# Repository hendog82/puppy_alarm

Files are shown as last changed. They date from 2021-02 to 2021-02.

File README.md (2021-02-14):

# Puppy Alarm Clock
Do you hate waking up to your alarm clock? Well, now you can wake up to your puppy licking your face instead. 

This gadget allows you to set a wake up time, and then it will open your dogs crate at the specified time, allowing your dog to jump on your bed and wake you up. 

### Firmware
The firmware is based on the [restful server example](https://github.com/espressif/esp-idf/tree/master/examples/protocols/http_server/restful_server) from the ESP-IDF. The firmware connects to the WiFi network and hosts a local website (so that any device connected to the same network can access it).

Users can connect to this local web page to set the alarm time (using post requests). The ESP gets the current time using NTP, and if the times match the ESP will turn on the motor, opening the dog create. 

### Webpage
The webpage has a live clock and selectable options to set the wake up time, which is then sent to the ESP 32 using a post request. The source code is in the `/front/web-demo/dist` folder.

### Hardware
I generated a simple 2-layer PCB using EAGLE. The files are in the `/board_files` folder. This PCB connects the [ESP-32 huzzah Dev board](https://www.adafruit.com/product/3405) to an H-Bridge that can drive the motor in either direction, and to a button that is used to reset the motor position (or any other desired function. It also has LED's to indicate motor spin direction. The board is powered using 5V from the micro-usb port on the dev board.

#### Pin Assignment:
The following GPIO's of the ESP32 Dev Board are connected

| ESP32  | Function |
| --- | --- |
| GPIO27 | Motor Forwards |
| GPIO33 | Motor Backwards|
| GPIO16 | Button Input |

### 3D Printed Housing
The STL files for the 3D printed housing are in the `/housing` folder.

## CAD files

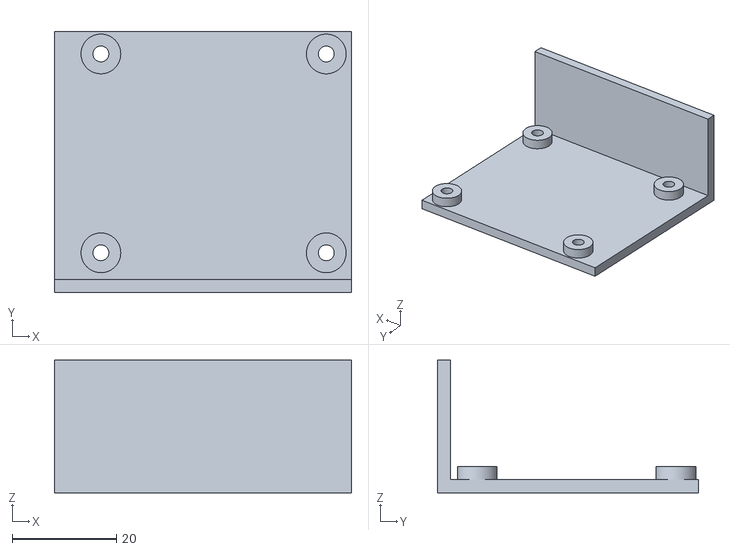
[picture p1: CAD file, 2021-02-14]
Housing/alarm housing v3.stl
56.9 x 50.0 x 25.4

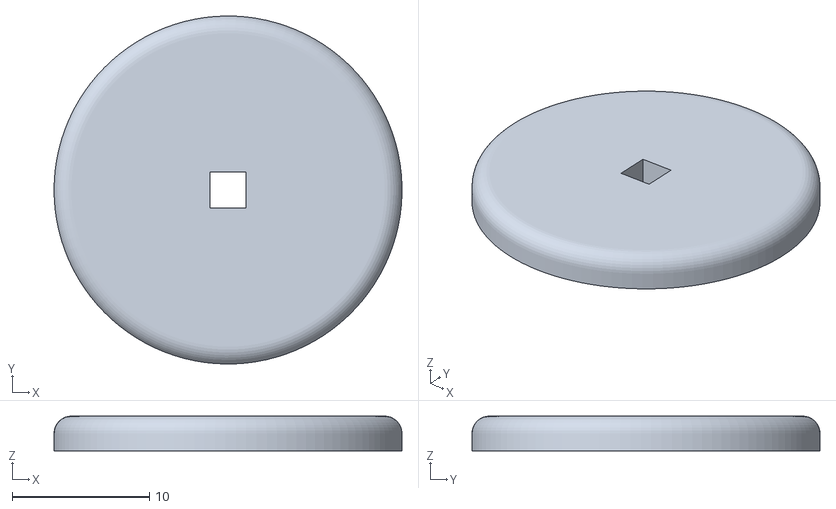
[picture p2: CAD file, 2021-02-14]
Housing/alarm wheel v1.stl
25.4 x 25.4 x 2.54

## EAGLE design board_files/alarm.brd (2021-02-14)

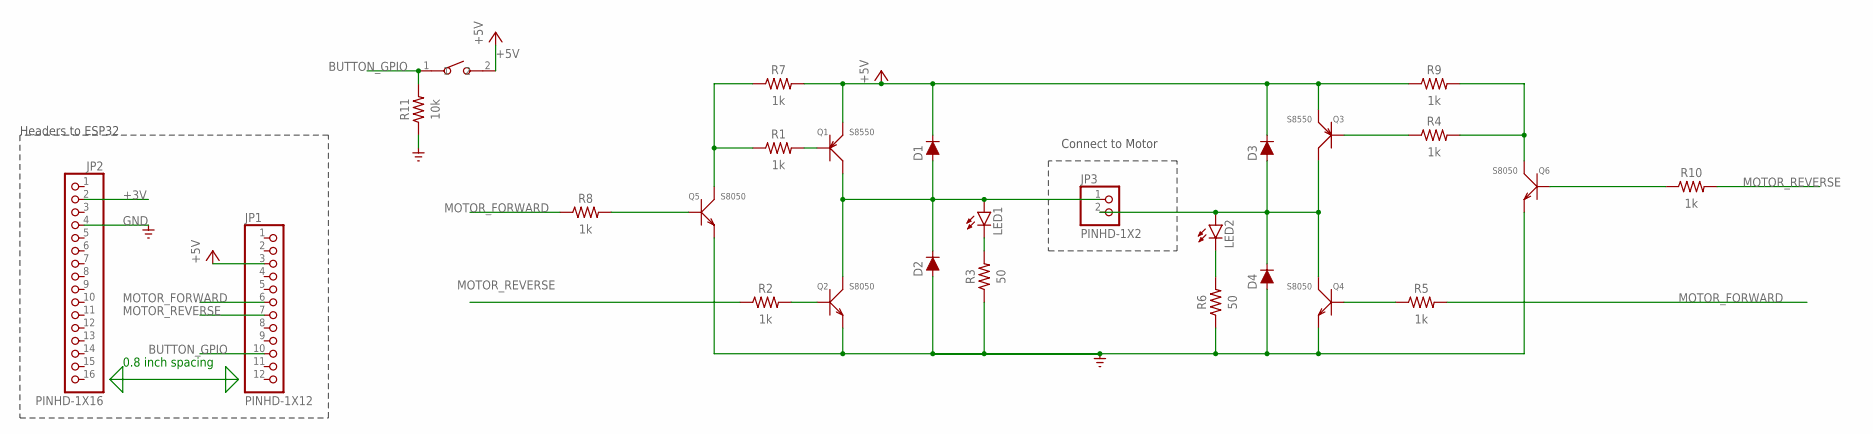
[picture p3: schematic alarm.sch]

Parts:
D1, D2, D3, D4: 250mA/100V; SOD-323
JP1: PINHD-1X12; 1X12
JP2: PINHD-1X16; 1X16
JP3: PINHD-1X2; 1X02
LED1: LED-GREEN0603; 0603-GREEN
LED2: LED-ORANGE0603; 0603-ORANGE
Q1, Q3: S8550; SOT-23
Q2, Q4, Q5, Q6: S8050; SOT-23
R1, R2, R4, R5, R7, R8, R9, R10: 1k; RESC1608X60
R3, R6: 50; RESC1608X60
R11: 10k; RESC1608X60
SW1: B3U-1000P-2P-SMD; SW2-2.6-3.0X2.5X1.2+0.4MM

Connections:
+3V: JP2.2
+5V: D1.C, D3.C, JP1.3, Q1.2 (E), Q3.2 (E), R7.2, R9.1, SW1.2
BUTTON_GPIO: JP1.10, R11.2, SW1.1
GND: D2.A, D4.A, JP2.4, Q2.2 (E), Q4.2 (E), Q5.2 (E), Q6.2 (E), R3.1, R6.1, R11.1
MOTOR_BLACK: D3.A, D4.C, JP3.2, LED2.A, Q3.3 (C), Q4.3 (C)
MOTOR_FORWARD: JP1.6, R5.2, R8.1
MOTOR_RED: D1.A, D2.C, JP3.1, LED1.A, Q1.3 (C), Q2.3 (C)
MOTOR_REVERSE: JP1.7, R2.1, R10.2
unnamed: Q1.1 (B), R1.2
unnamed: Q2.1 (B), R2.2
unnamed: LED1.C, R3.2
unnamed: Q5.1 (B), R8.2
unnamed: Q3.1 (B), R4.1
unnamed: Q4.1 (B), R5.1
unnamed: LED2.C, R6.2
unnamed: Q5.3 (C), R1.1, R7.1
unnamed: Q6.3 (C), R4.2, R9.2
unnamed: Q6.1 (B), R10.1

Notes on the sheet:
0.8 inch spacing
Headers to ESP32
Connect to Motor

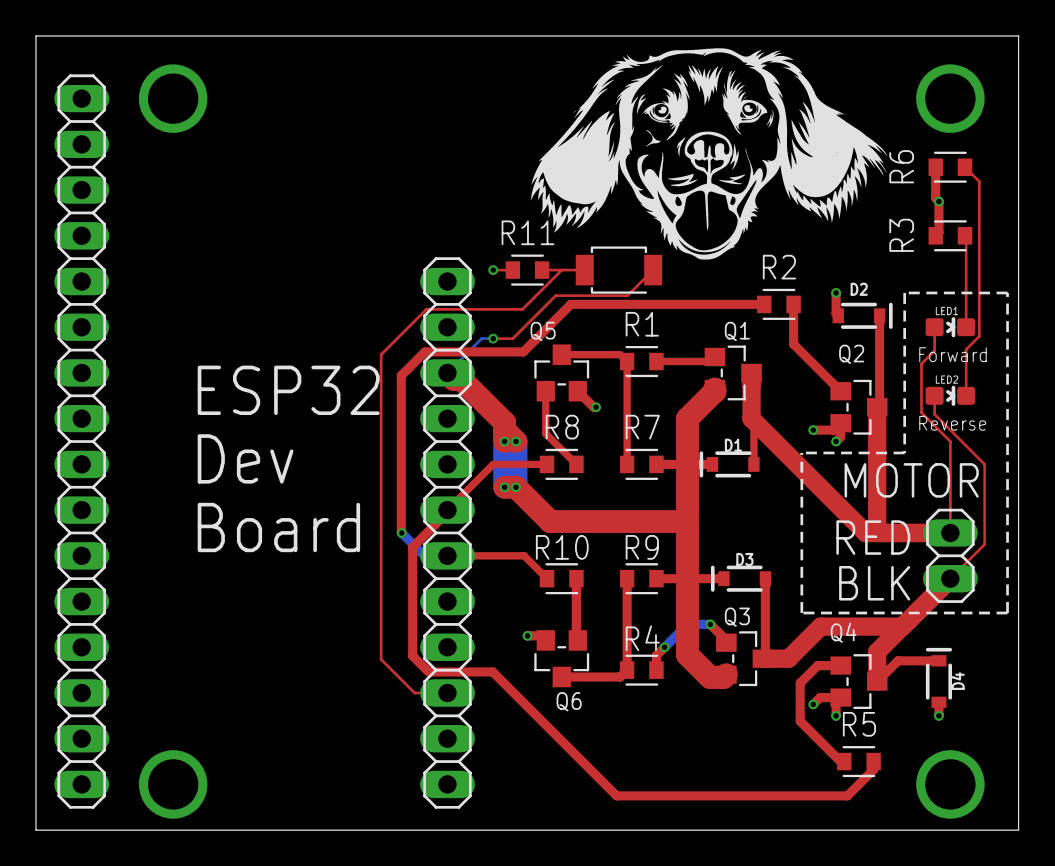
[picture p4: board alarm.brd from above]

Board: 2 copper layers, 54.6 x 44.1 mm, 27 parts (0 on the bottom side), 17 nets.

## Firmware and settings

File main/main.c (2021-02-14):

#include "sdkconfig.h"
#include <time.h>
#include <sys/time.h>
#include "driver/gpio.h"
#include "esp_vfs_semihost.h"
#include "esp_vfs_fat.h"
#include "esp_spiffs.h"
#include "sdmmc_cmd.h"
#include "nvs_flash.h"
#include "esp_netif.h"
#include "esp_event.h"
#include "esp_log.h"
#include "esp_sntp.h"

#include "server.h"
#include "gpio_if.h"

#include "mdns.h"
#include "lwip/apps/netbiosns.h"
#include "protocol_examples_common.h"
#if CONFIG_EXAMPLE_WEB_DEPLOY_SD
#include "driver/sdmmc_host.h"
#endif

#define MDNS_INSTANCE "esp home web server"

static const char *TAG = "main";


static void initialise_mdns(void)
{
    mdns_init();
    mdns_hostname_set(CONFIG_EXAMPLE_MDNS_HOST_NAME);
    mdns_instance_name_set(MDNS_INSTANCE);

    mdns_txt_item_t serviceTxtData[] = {
        {"board", "esp32"},
        {"path", "/"}
    };

    ESP_ERROR_CHECK(mdns_service_add("ESP32-WebServer", "_http", "_tcp", 80, serviceTxtData,
                                     sizeof(serviceTxtData) / sizeof(serviceTxtData[0])));
}

#if CONFIG_EXAMPLE_WEB_DEPLOY_SEMIHOST
esp_err_t init_fs(void)
{
    esp_err_t ret = esp_vfs_semihost_register(CONFIG_EXAMPLE_WEB_MOUNT_POINT, CONFIG_EXAMPLE_HOST_PATH_TO_MOUNT);
    if (ret != ESP_OK) {
        ESP_LOGE(TAG, "Failed to register semihost driver (%s)!", esp_err_to_name(ret));
        return ESP_FAIL;
    }
    return ESP_OK;
}
#endif

#if CONFIG_EXAMPLE_WEB_DEPLOY_SD
esp_err_t init_fs(void)
{
    sdmmc_host_t host = SDMMC_HOST_DEFAULT();
    sdmmc_slot_config_t slot_config = SDMMC_SLOT_CONFIG_DEFAULT();

    gpio_set_pull_mode(15, GPIO_PULLUP_ONLY); // CMD
    gpio_set_pull_mode(2, GPIO_PULLUP_ONLY);  // D0
    gpio_set_pull_mode(4, GPIO_PULLUP_ONLY);  // D1
    gpio_set_pull_mode(12, GPIO_PULLUP_ONLY); // D2
    gpio_set_pull_mode(13, GPIO_PULLUP_ONLY); // D3

    esp_vfs_fat_sdmmc_mount_config_t mount_config = {
        .format_if_mount_failed = true,
        .max_files = 4,
        .allocation_unit_size = 16 * 1024
    };

    sdmmc_card_t *card;
    esp_err_t ret = esp_vfs_fat_sdmmc_mount(CONFIG_EXAMPLE_WEB_MOUNT_POINT, &host, &slot_config, &mount_config, &card);
    if (ret != ESP_OK) {
        if (ret == ESP_FAIL) {
            ESP_LOGE(TAG, "Failed to mount filesystem.");
        } else {
            ESP_LOGE(TAG, "Failed to initialize the card (%s)", esp_err_to_name(ret));
        }
        return ESP_FAIL;
    }
    /* print card info if mount successfully */
    sdmmc_card_print_info(stdout, card);
    return ESP_OK;
}
#endif

#if CONFIG_EXAMPLE_WEB_DEPLOY_SF
esp_err_t init_fs(void)
{
    esp_vfs_spiffs_conf_t conf = {
        .base_path = CONFIG_EXAMPLE_WEB_MOUNT_POINT,
        .partition_label = NULL,
        .max_files = 5,
        .format_if_mount_failed = false
    };
    esp_err_t ret = esp_vfs_spiffs_register(&conf);

    if (ret != ESP_OK) {
        if (ret == ESP_FAIL) {
            ESP_LOGE(TAG, "Failed to mount or format filesystem");
        } else if (ret == ESP_ERR_NOT_FOUND) {
            ESP_LOGE(TAG, "Failed to find SPIFFS partition");
        } else {
            ESP_LOGE(TAG, "Failed to initialize SPIFFS (%s)", esp_err_to_name(ret));
        }
        return ESP_FAIL;
    }

    size_t total = 0, used = 0;
    ret = esp_spiffs_info(NULL, &total, &used);
    if (ret != ESP_OK) {
        ESP_LOGE(TAG, "Failed to get SPIFFS partition information (%s)", esp_err_to_name(ret));
    } else {
        ESP_LOGI(TAG, "Partition size: total: %d, used: %d", total, used);
    }
    return ESP_OK;
}
#endif


void app_main(void)
{
    ESP_ERROR_CHECK(nvs_flash_init());
    ESP_ERROR_CHECK(esp_netif_init());
    ESP_ERROR_CHECK(esp_event_loop_create_default());
    initialise_mdns();
    netbiosns_init();
    netbiosns_set_name(CONFIG_EXAMPLE_MDNS_HOST_NAME);

    ESP_ERROR_CHECK(example_connect());
    ESP_ERROR_CHECK(init_fs());
    ESP_ERROR_CHECK(start_rest_server(CONFIG_EXAMPLE_WEB_MOUNT_POINT));

    ESP_LOGI(TAG, "Getting Current Time using NTP");

    sntp_setoperatingmode(SNTP_OPMODE_POLL);
    sntp_setservername(0, "pool.ntp.org");
    sntp_init();


    sleep(5);
    struct timeval tv_now;

    //FIXME: Time zone won't be correct after daylight savings time
    gettimeofday(&tv_now, "MST7MDT");

    time_t now;
    char strftime_buf[64];
    struct tm timeinfo;


    time(&now);
    //FIXME: Time zone won't be correct after daylight savings time
    //timeinfo.tm_isdst can be used to correct daylight savings time
    setenv("TZ", "MST7MDT", 1);
    tzset();

    localtime_r(&now, &timeinfo);
    strftime(strftime_buf, sizeof(strftime_buf), "%c", &timeinfo);

    //printf("Daylight savings time = %x\r\n", timeinfo.tm_isdst);


    ESP_LOGI(TAG, "The current date/time is: %s", strftime_buf);
    gpio_init();
    while(1){
    	sleep(3);
        time(&now);
        localtime_r(&now, &timeinfo);

    	int hour = timeinfo.tm_hour;
    	int minute = timeinfo.tm_min;

        ESP_LOGI(TAG, "The current time is: %i:%02i", hour, minute);
        alarm_state_t alarm_state = compare_time(hour, minute);
        if (alarm_state == Alarm_Trig){
            ESP_LOGI(TAG, "Wake Up Time!!!");
            motor_forward();
            disable_alarm();
        }
        //motor_forward();
    }
}

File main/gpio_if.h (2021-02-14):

#define MOTOR_FORWARD_GPIO		27
#define MOTOR_REVERSE_GPIO		33
#define BUTTON_GPIO				14

#define GPIO_OUTPUT_PIN_SEL  ((1ULL<<MOTOR_FORWARD_GPIO)|(1ULL<<MOTOR_REVERSE_GPIO))
#define GPIO_INPUT_PIN_SEL   (1ULL<<BUTTON_GPIO)


/*
 * Initializes all motor and button functions:
 *
 * 		(1) calls motor_init(), button_init(),
 * 		(2) sets up button isr handler
 * 		(3) starts button task.
 *
 */
void gpio_init();

/*
 * initialize motor gpios
 */
void motor_init();

/*
 * interrupt handler for button
 */
void button_isr_handler(void* arg);

/*
 * task to receive button interrupts.
 */
void Button_Task(void* arg);

/*
 * initialize button gpio
 */
void button_init();

/*
 * spin motor forwards for 3 seconds
 */
void motor_forward();

/*
 * spin motor backwards for 3 seconds
 */
void motor_reverse();

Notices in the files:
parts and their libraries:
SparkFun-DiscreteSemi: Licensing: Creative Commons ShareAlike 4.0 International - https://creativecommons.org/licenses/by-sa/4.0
